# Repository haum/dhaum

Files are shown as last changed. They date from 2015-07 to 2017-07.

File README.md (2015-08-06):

# dHAUM

The dHAUM is a geodetic structure which can be used as a base for several projects.

The geodetic dome itself is a 5/8eme of a sphere structure, assembled using :

- 95 pieces of wood of 2 different types
- 36 connectors of 4 different types
- 190 bolts, nuts and washers

## Use cases

The dHAUM have been used to :

- create a huge group-played musical instrument : the [dHAUMidi](https://github.com/haum/dhaumidi)

## Repository

- ``doc/`` : documentation (build report, model, blueprint, etc...)
- ``parts/`` : DXF and milling gcodes for parts of the dome itself
- ``tools/ : DXF and milling gcodes for tools used to machine the wooden parts

Computation are done using the software [Zome Dome & Cie](http://www.ardheia.fr/ardheia/index.php/ressources).

Inside the ``doc/`` folder, you'll find :

- ``dHaum.zdc`` project file for the software
- ``Geodome.pdf`` building report generated by ZDC
- ``developpe.pdf``& ``developpe.dxf`` global plane developpement
- ``patron_4imp.pdf`` file to print 5 times to build a mock-up of the dHAUM at a 1/12.5 scale.
    Gluing works this way : capital letters must be glued on another print, lowercase letters must be glued on the same print but no strips are drawn : create yours. You should start by A, then B, a, C, D and finally b.

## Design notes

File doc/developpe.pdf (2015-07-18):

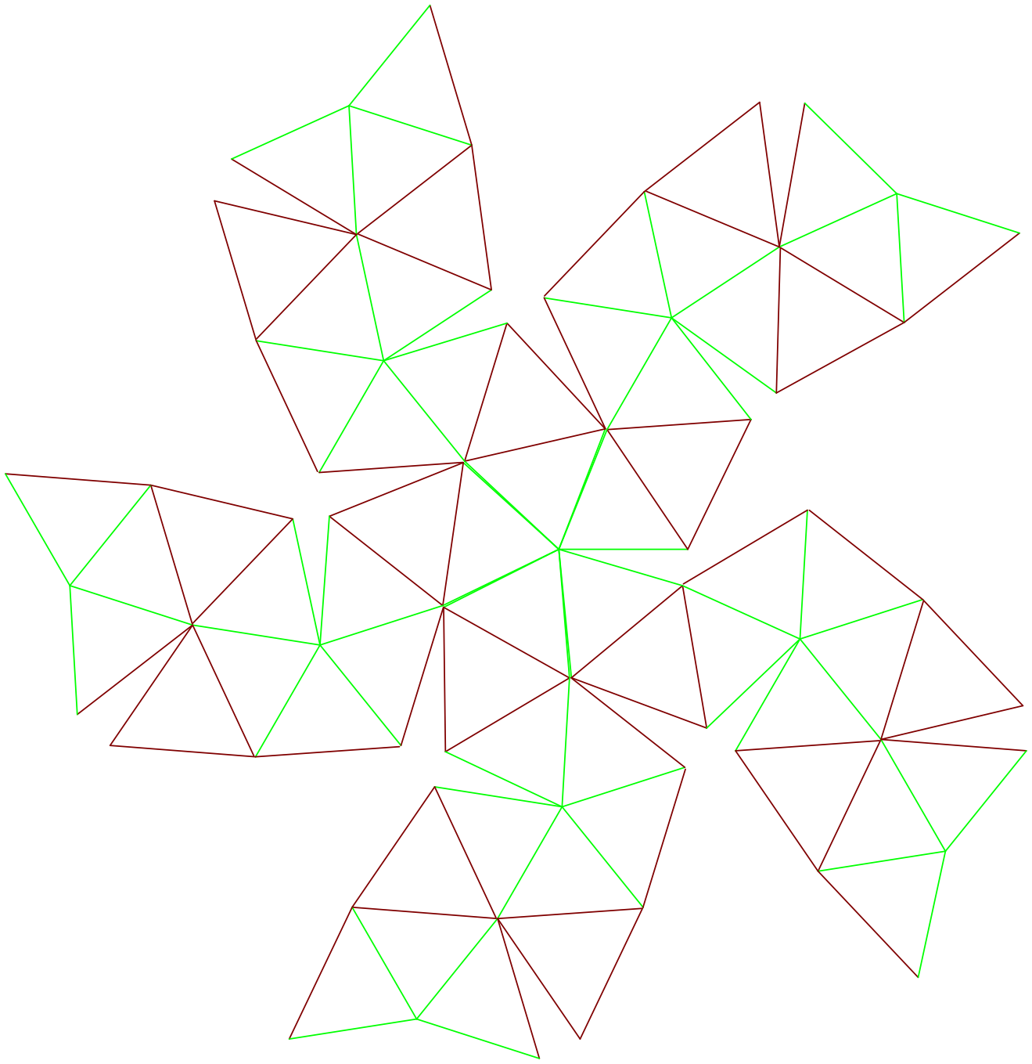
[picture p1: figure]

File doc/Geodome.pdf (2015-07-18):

# Compte-rendu technique d'un Geodome V 2 0

## Document généré automatiquement par le logiciel ZomeDomeEtCie (version 15.03.05)

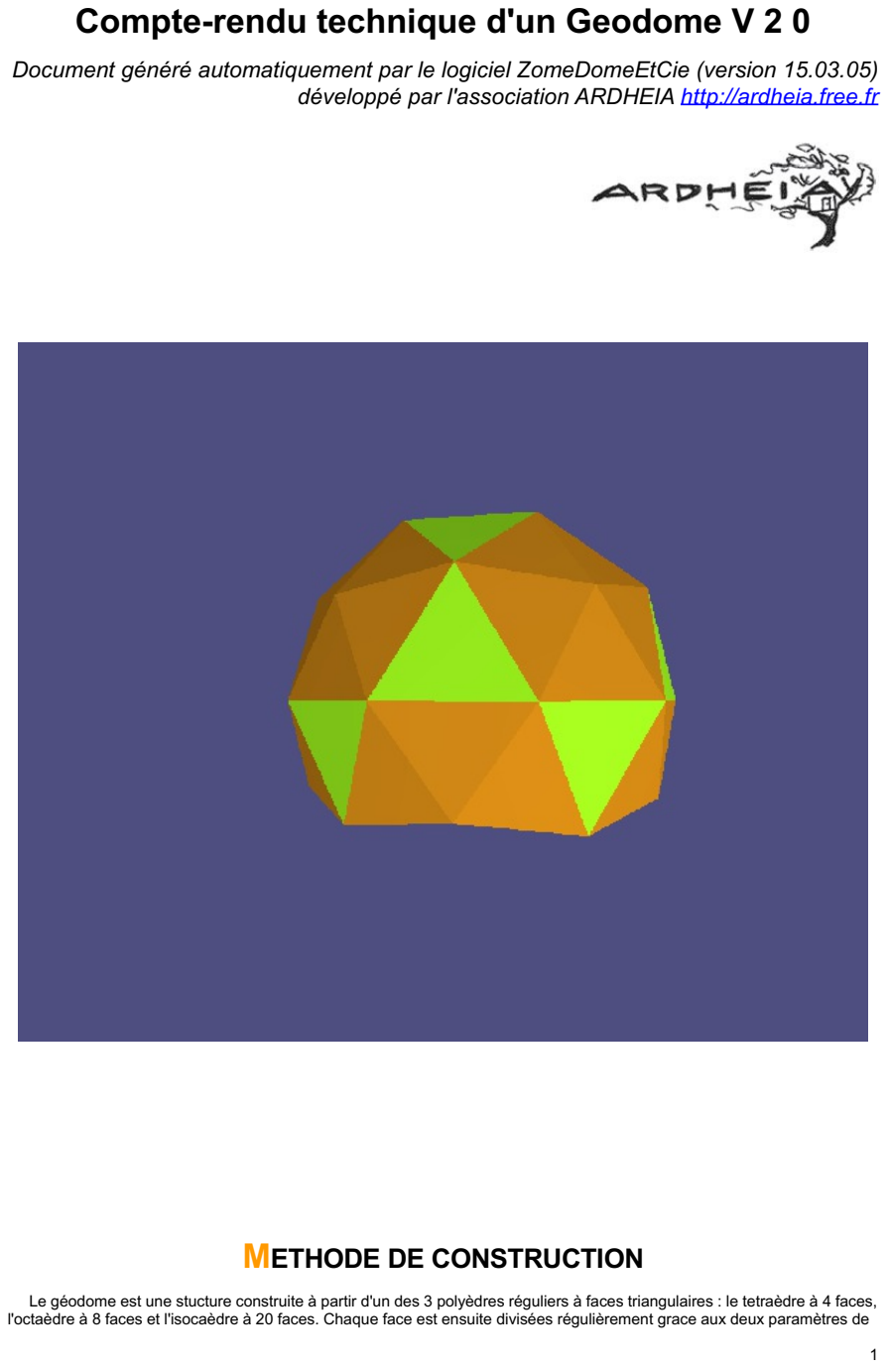
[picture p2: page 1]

## développé par l'association ARDHEIA http://ardheia.free.fr

## METHODE DE CONSTRUCTION

Le géodome est une stucture construite à partir d'un des 3 polyèdres réguliers à faces triangulaires : le tetraèdre à 4 faces, l'octaèdre à 8 faces et l'isocaèdre à 20 faces. Chaque face est ensuite divisées régulièrement grace aux deux paramètres de fréquence A et B. Les points obtenus sont ensuite projetés sur une sphère et reliés entre eux. Différentes méthodes sont possibles pour construire et assembler des géodomes. La documentation concernant les

géodomes (ou géodes, ou domes géodesiques) est abondante sur internet. Rappel des paramètres constructifs importants :

- Type de géodome : V 2 0 (chiffres romains pour indiquer solide de base : III pour tetraedre, IV pour octaedre, V pour isocaèdre; deuxième et troisième chiffres : fréquence A et fréquence B)
- Diamètre au sol, pour implantation : 2.38 m
- Diamètre de la sphère : 2.80 m
- Hauteur réelle, jusqu'au faîtage : 2.14 m
- Sablière horizontale : non
- Angle de rotation : 32°
- Surface au sol : 4.46 m²
- Surface de couverture : 17.15 m²
- Volume approché : 9.86 m3

## FACES

Le tableau suivant détaille les faces (f) du géodome : pour chaque type, il donne le nombre d'éléments, la surface, le type des 3 arêtes qui la constitue, leurs longueurs respectives, les mesures des 3 angles du triangle ainsi que la côte H qui peut être utile pour tracer les faces. Surface totale des faces (donc de toute la couverture du géodome) : 17.1 m². Les schémas suivants le tableau sont dessinés avec les bonnes côtes et angles, mais à échelle réduite bien sur.

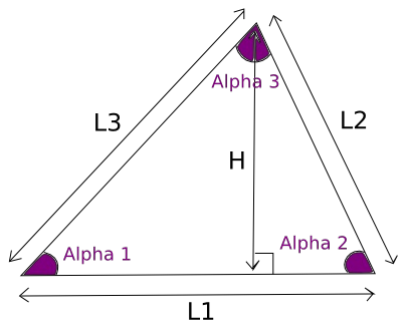
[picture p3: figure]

Type | Nombre | Surface (m2) | Type Arêtes | L1 (cm) | L2 (cm) | L3 (cm) | H (cm) | Alpha 1 (°) | Alpha 2 (°) | Alpha3 (°)

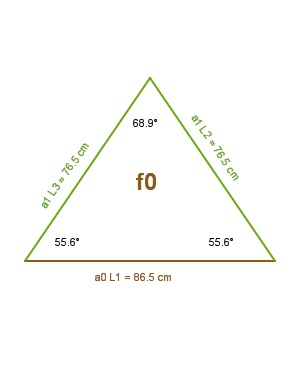
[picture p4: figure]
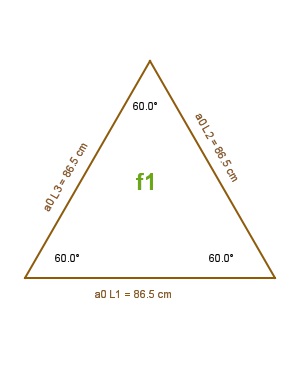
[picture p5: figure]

f0 | 45 | 0.27 | 0->1->1 | 86.5 | 76.5 | 76.5 | 63.1 | 55.6 | 55.6 | 68.9
f1 | 15 | 0.32 | 0->0->0 | 86.5 | 86.5 | 86.5 | 74.9 | 60.0 | 60.0 | 60.0
TOTAL | 60 | 17.15

## ARETES

Le tableau suivant détaille les arêtes (a) du géodome : pour chaque type, il donne le nombre d'éléments, leur longueur, ainsi que l'angle de bout. Cet angle est celui avec lequel il vont arriver sur le connecteur. Si vous travaillez avec des montants

en bois, il correspond à l'angle d'inclinaison de la scie pour couper les extrémités du montant. Attention, les longueurs sont données sans prendre en compte les éventuelles dimensions des connecteurs. Il faudra donc

en tenir compte pour tailler les montants, sinon vous allez simplement vous retrouver avec un géodome un peu plus grand. Métrage linéaire des montants (à multiplier par la section de vos montants pour avoir le débit) : 77.19 m.

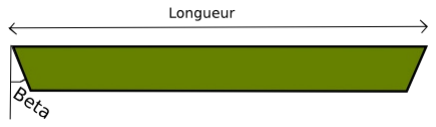
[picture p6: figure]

Type | Nombre | Longueur (cm) | Beta (°) | Rapport Longueur
a0 | 45 | 86.5 | 18.0 | 0.309017
a1 | 50 | 76.5 | 15.9 | 0.273267
TOTAL | 95 | 77.19 m

## SOMMETS

Le tableau suivant détaille les sommets (s) du géodome (ou connecteurs) : pour chaque type, il donne le nombre d'éléments, s'ils représentent un noeud complet ou un noeud qui n'a pas de faces tout autour de lui, le type des arêtes qui partent de ce noeud, le type des faces autour de ce noeud et les angles alpha'. Les données précedentes sont données pour chaque noeud, en tournant dans le sens horaire si on regarde le noeud depuis l'extérieur du géodome. Attention, les angles alpha' sont les angles projetés sur une surface plane (leur somme fait 360°), ce ne sont pas les

angles des différentes faces, ces derniers étant un peu inférieurs et donnés à l'onglet faces

Les schémas suivants le tableau sont dessinés avec les bons angles. Type | Nombre | Complet | Type Arêtes | Type Faces | Angles Alpha' ° s0 | 6 | oui | a1->a1->a1->a1->a1-> | f0->f0->f0->f0->f0-> | 72.0°->72.0°->72.0°->72.0°->72.0°->
s1 | 20 | oui | a0->a1->a0->a0->a1->a0-> | f0->f0->f1->f0->f0->f1-> | 58.3°->58.3°->63.4°->58.3°->58.3°- >63.4°->
s2 | 3 | non | a1->a1->a1->a1 | f0->f0->f0 | 72.0°->72.0°->72.0° s3 | 5 | non | a1->a0->a0->a1 | f0->f1->f0 | 58.3°->63.4°->58.3° s4 | 2 | non | a1->a1->a1 | f0->f0->f-1 | 72.0°->72.0° TOTAL | 36

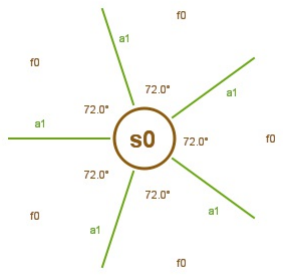
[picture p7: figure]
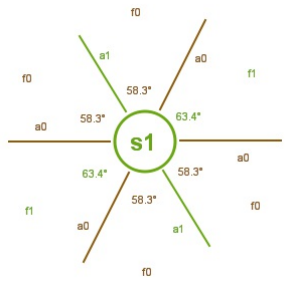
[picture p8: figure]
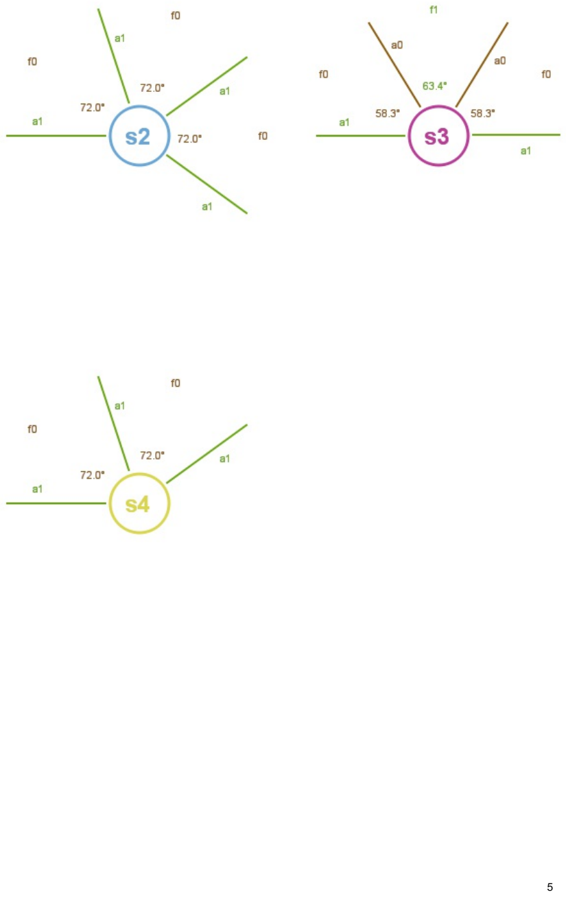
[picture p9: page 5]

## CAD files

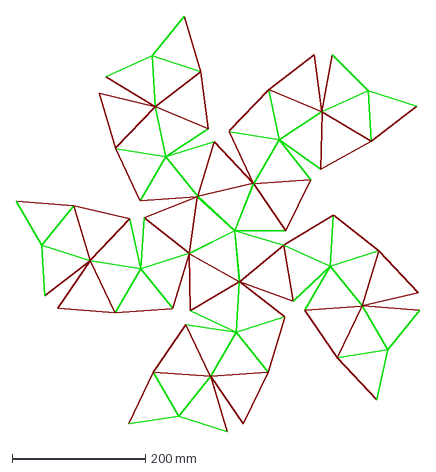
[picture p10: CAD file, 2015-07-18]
doc/developpe.dxf
605.8 x 624.2 mm

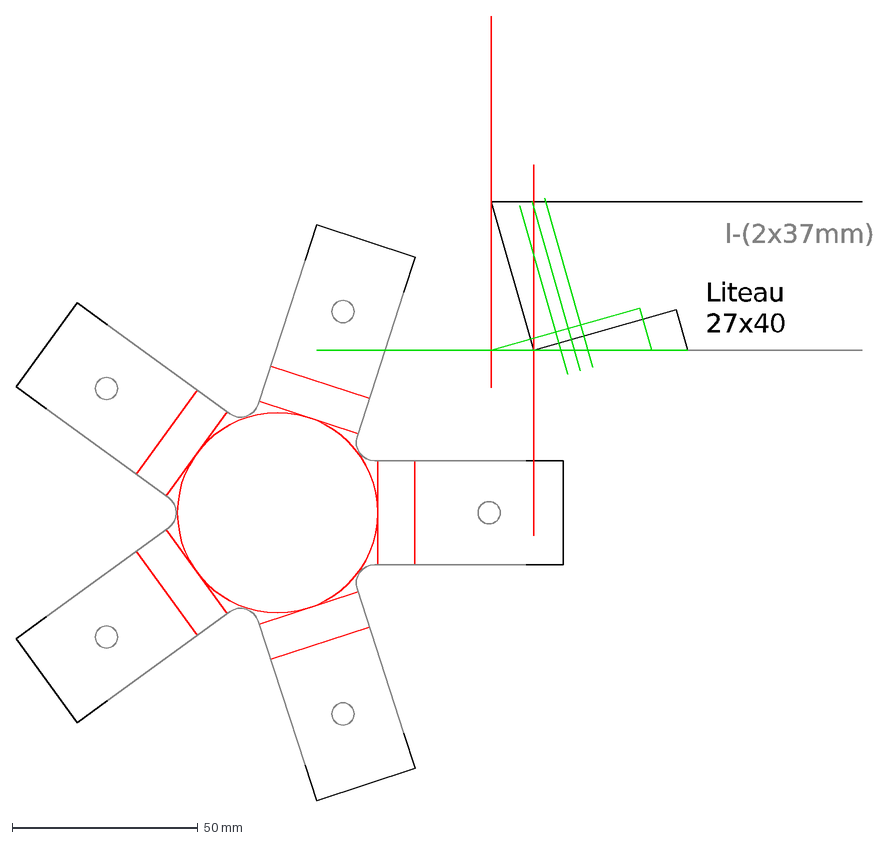
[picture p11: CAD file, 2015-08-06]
parts/connecteur0.dxf
l-(2x37mm)
Liteau 27x40

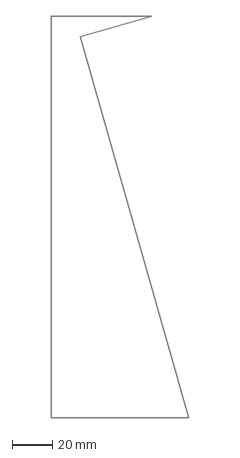
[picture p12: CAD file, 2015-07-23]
tools/sabot_15.9degres.dxf
68.5 x 200.0 mm

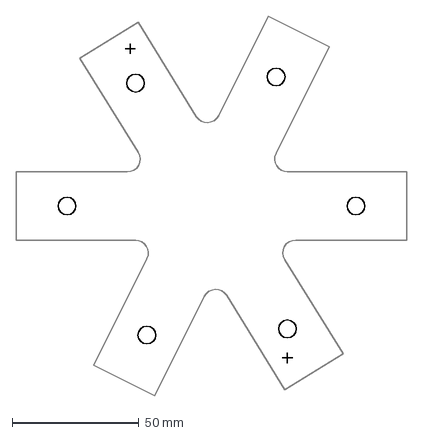
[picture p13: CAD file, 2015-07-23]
parts/connecteur1.dxf
154.0 x 149.8 mm

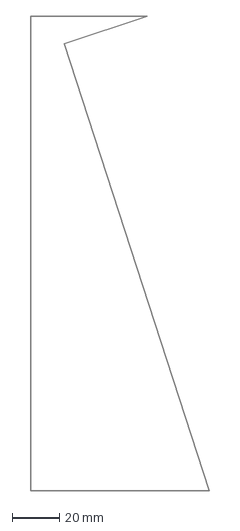
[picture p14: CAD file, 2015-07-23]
tools/sabot_18degres.dxf
75.3 x 200.0 mm

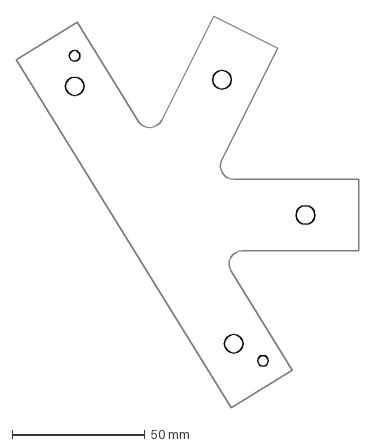
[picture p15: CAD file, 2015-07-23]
parts/connecteur3.dxf
128.9 x 147.5 mm

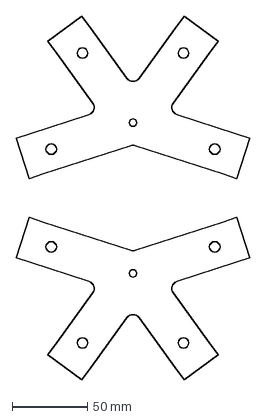
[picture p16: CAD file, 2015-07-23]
parts/connecteur24.dxf
155.1 x 241.0 mm

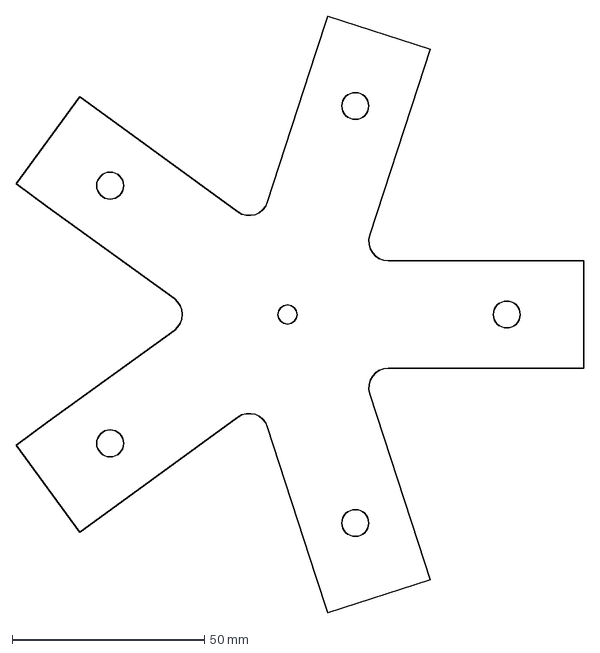
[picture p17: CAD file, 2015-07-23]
parts/connecteur0_cnc.dxf
147.5 x 155.1 mm

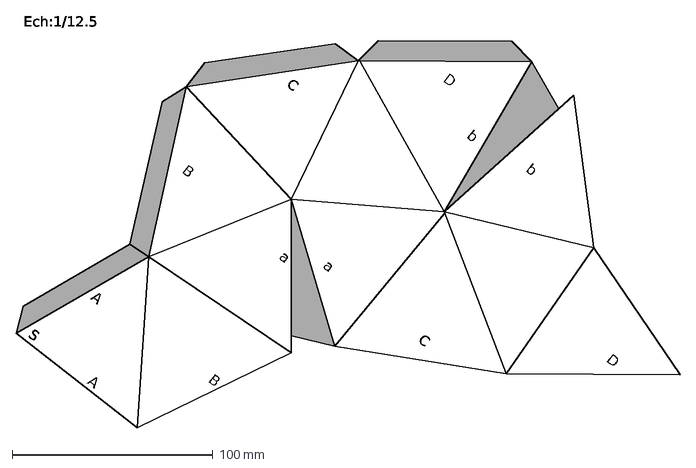
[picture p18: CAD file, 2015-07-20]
parts/geodHaum2_4imp.dxf
S
A
B
a
b
C
D
Ech:1/12.5

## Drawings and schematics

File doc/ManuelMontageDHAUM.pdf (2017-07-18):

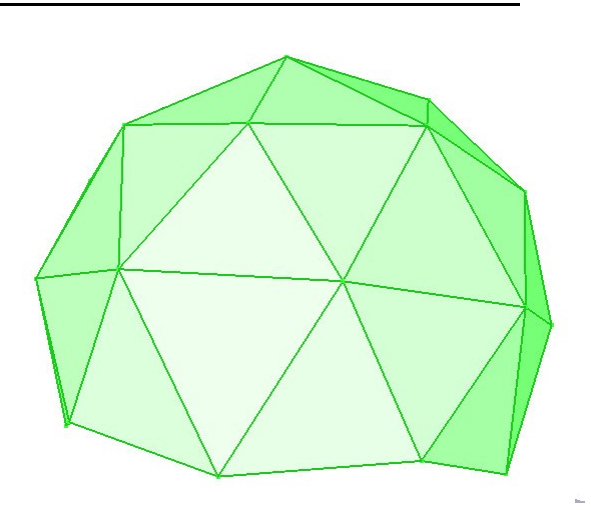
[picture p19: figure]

# Guide d'assemblage du dHAUM

### 1. Assemblage

Le dHAUM reproduit les 5/8 d'une sphère, en concéquence afin de faciliter la lecture des intructions de montage, ces dernières sont séparées en deux partie.

A. En partant de la base du dHAUM jusque son diamètre maxi. (a l'équateur).
B. Puis de ce point jusqu'au sommet

Légende :

Tasseaux courts
Tasseaux Longs
Connecteurs de type 1 (6 branches)

Connecteurs de type 2 (5 branches)

Connecteurs de type 3 (4 branches droit)

Connecteurs de type 4 (4 branches bas)

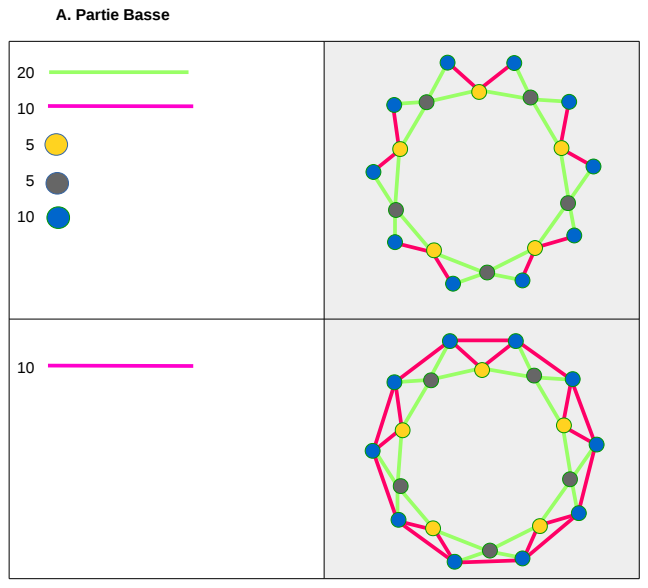
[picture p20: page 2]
A. Partie Basse

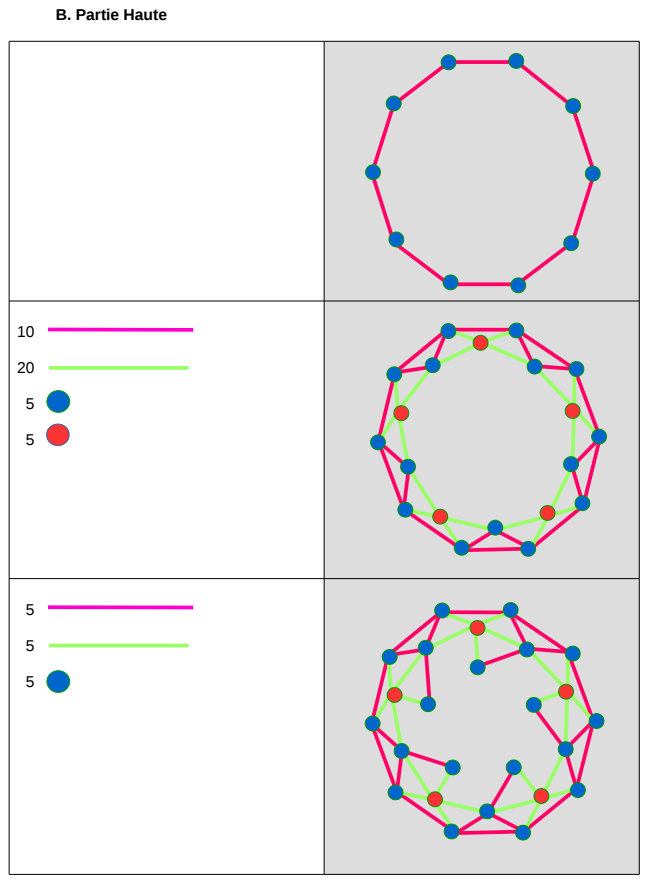
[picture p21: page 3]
B. Partie Haute

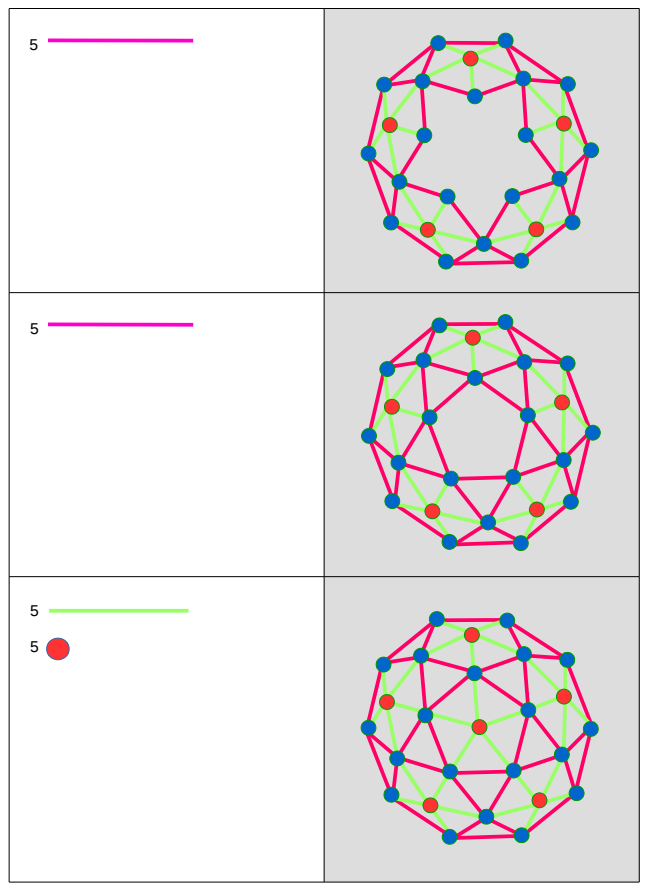
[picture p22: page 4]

### 2. Portes et Entoilage

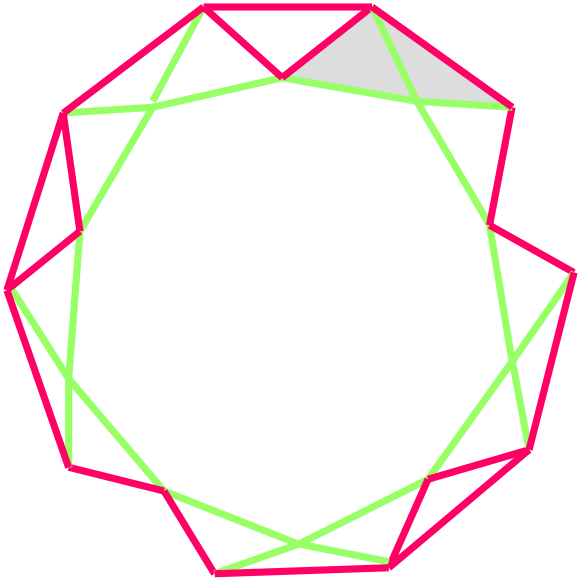
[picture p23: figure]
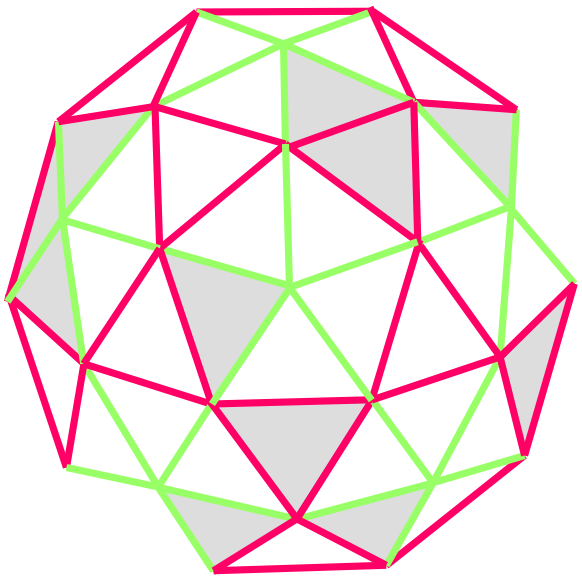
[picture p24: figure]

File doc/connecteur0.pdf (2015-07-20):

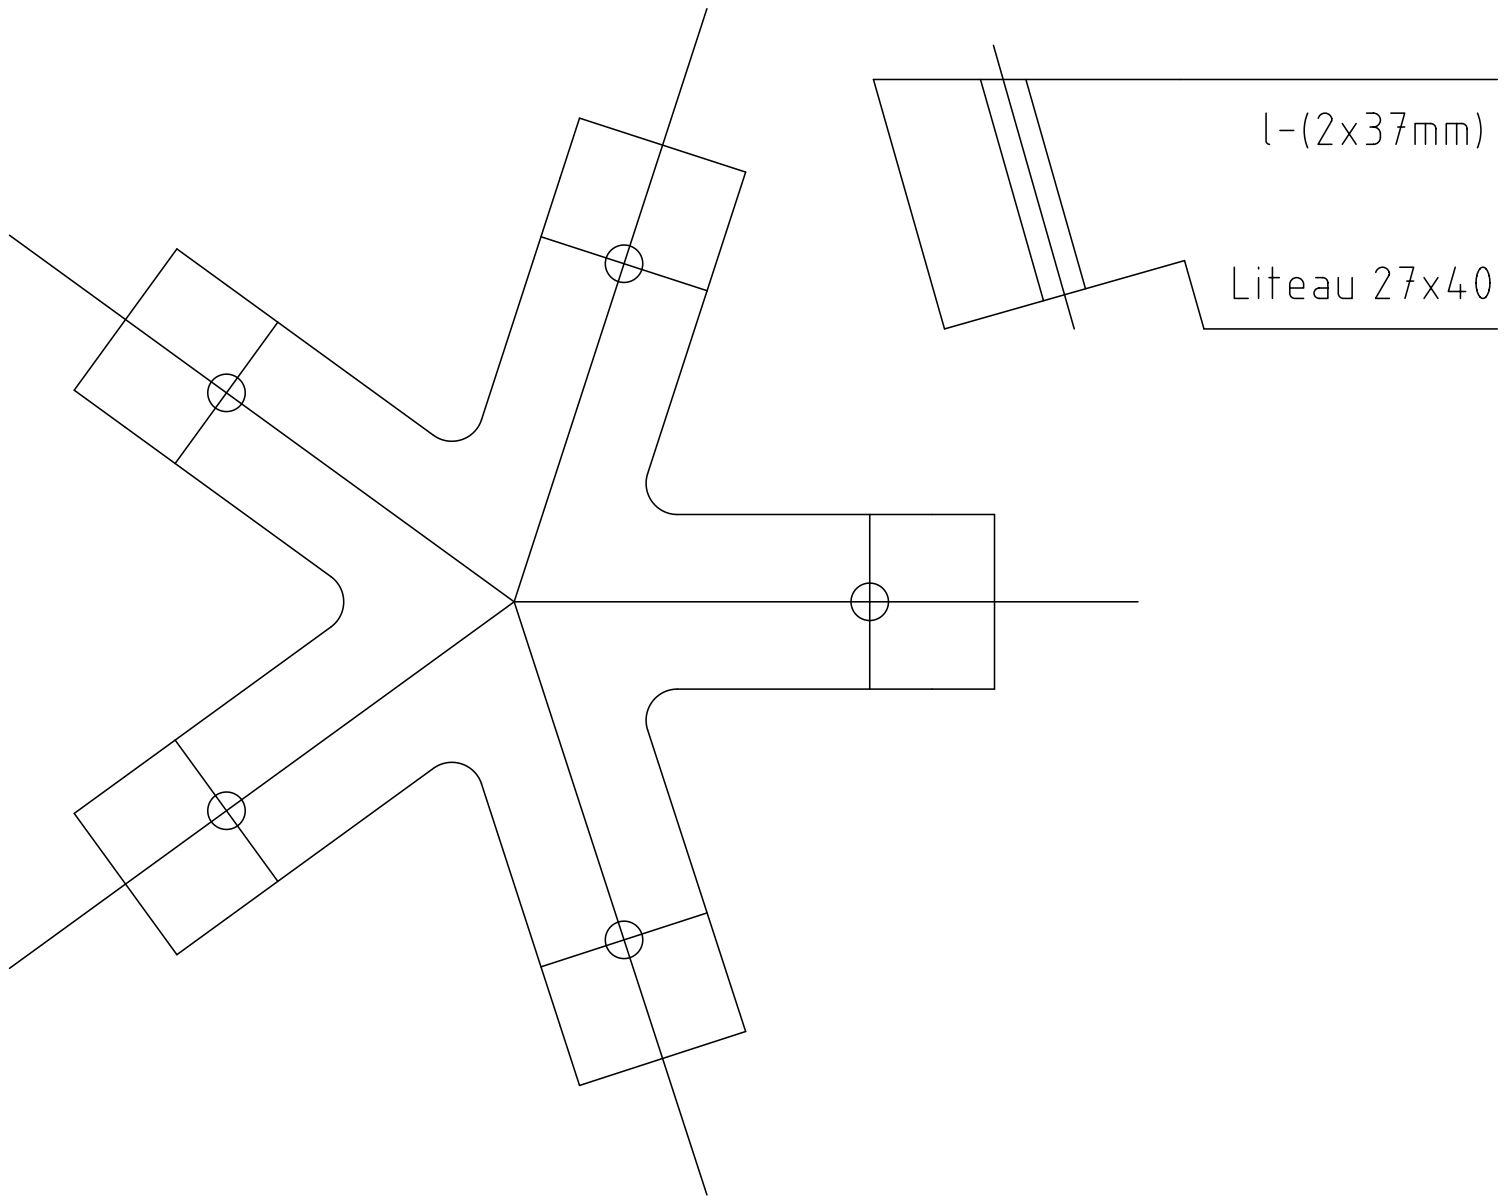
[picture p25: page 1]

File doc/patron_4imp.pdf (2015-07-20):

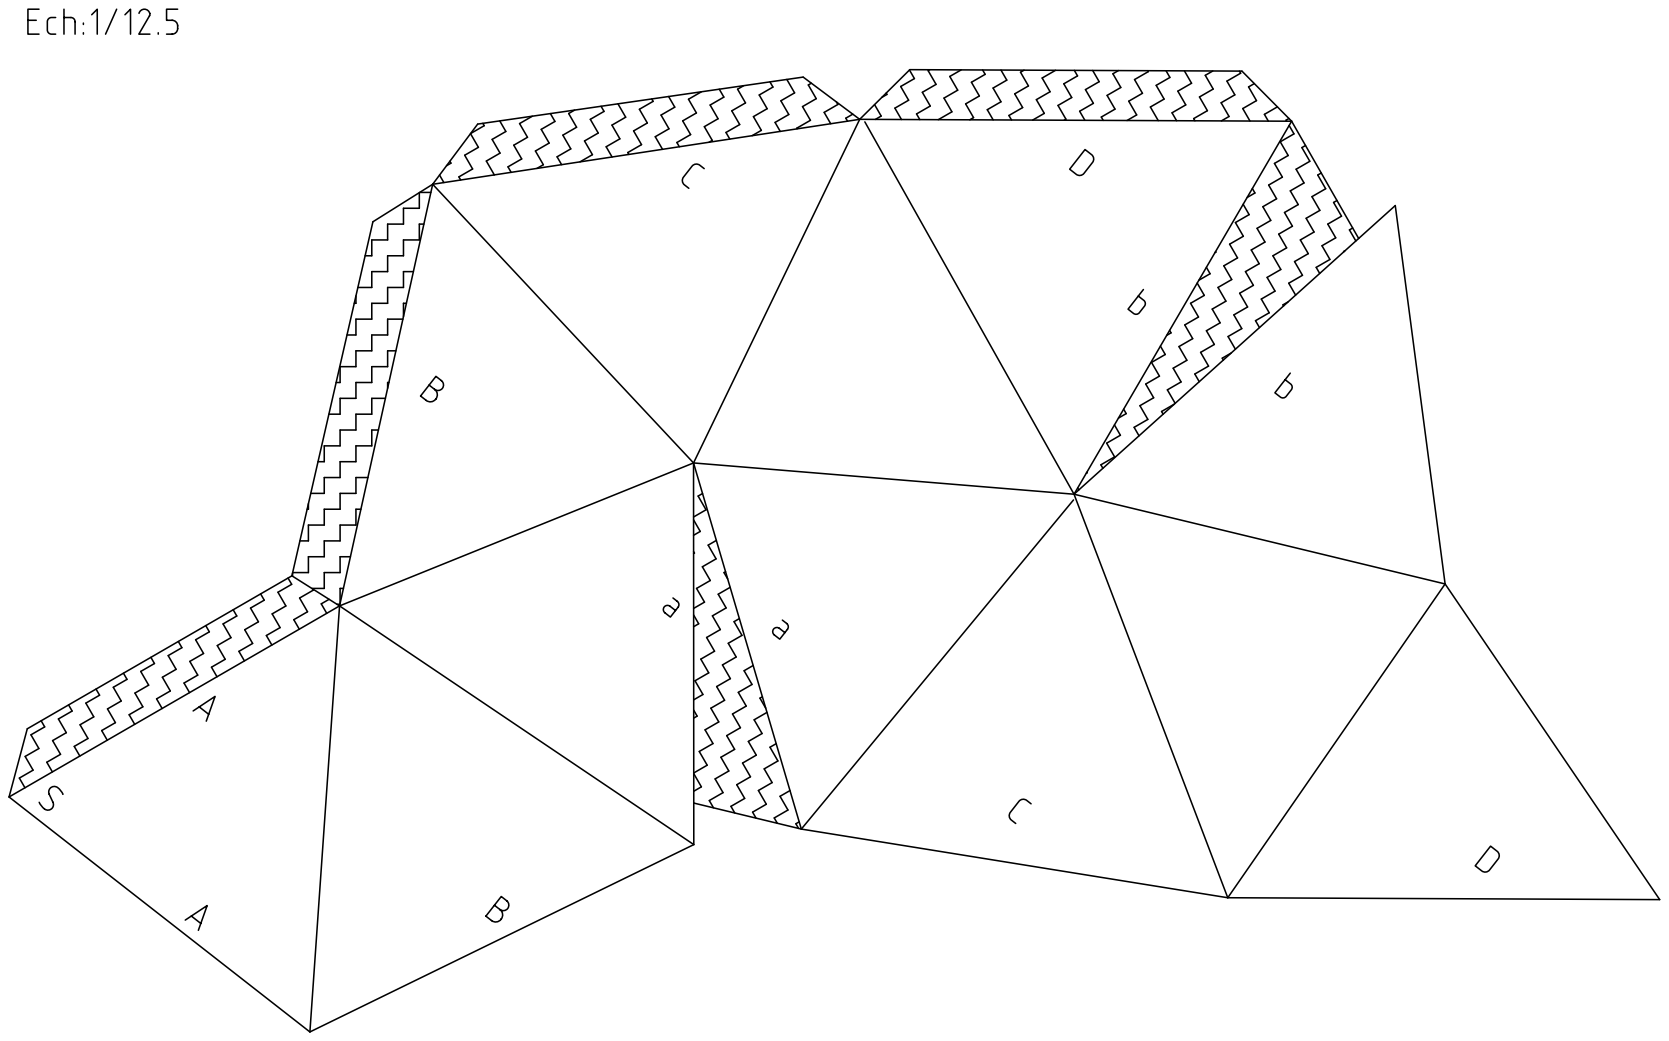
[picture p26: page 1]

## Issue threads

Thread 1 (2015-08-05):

Ajouter une sortie hardware MIDI

jblb, 2015-08-05:
il s'agit, en plus de la connexion MIDI a travers l'USB, de disposer d'une sortie MIDI sur une prise Dim/5broches qui sorte les même valeurs MIDI que l'interface USB. De cette façon deux récepteurs peuvent utiliser le code généré par l'interface.

JackDesBwa, 2015-08-05:
Il y a une seule broche de la Léoké qui n'est pas utilisable avec les
touches "tactiles". Elle est numérotée L0 et doit être au niveau logique
bas au démarrage de la carte (il y a une pull-down) pour que ça démarre au
bon endroit dans la flash. Elle peut parfaitement être employée en sortie
si l'impédance en face est compatible.

Après faudrait trouver une lib qui puisse générer un signal midi sur une
gpio sans occuper trop de CPU. Ou alors sacrifier des broches pour utiliser
une vraie liaison série.

Sinon on peut aussi faire un pass-through sur le PC, ce serait certainement
moins contraignant.
Le 5 août 2015 11:05, "JbLb" <notifications@github.com> a écrit :

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

neomilium, 2015-08-05:
Le MIDI 'old-school' est plus ou moins un UART à 31250 bauds. Il faut donc utiliser les pins UART pour faire cela sans trop consommer de CPU.

Pour ma part, je ne vois pas l'intérêt : pourquoi ne pas passer par l'ordinateur qui multiplexe ensuite vers autant de sorties qu'utiles, avec ou sans transformation intermédiaire :)

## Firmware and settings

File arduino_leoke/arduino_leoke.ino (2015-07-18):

/* To be used with Léoké */

#define PADBIT(PAD) (1 << (PAD-1))
#define PADSNB (sizeof(L)/sizeof(*L))

#define DEBUG_RAW_CODE 0

typedef enum {
  UNTOUCHED, // Not touched at all
  TOUCHED, // Touched this loop
  LASTTOUCHED, // Touched last loop
} touchstatus_e;

struct binder_s {
  uint32_t bits;
  uint32_t mask;

  touchstatus_e touched;
  char debounce;
  touchstatus_e touched_filtered;
} binders[] = {
  { PADBIT(1) | PADBIT(2), 0xffffffff, },
  { PADBIT(5) | PADBIT(6), 0xffffffff, },
};

#define BINDERNB (sizeof(binders)/sizeof(*binders))
#define MAXDEBOUNCE 5

void setup() {
  // All others are input and untouched
  for (int i = 0; i < PADSNB; ++i) {
    pinMode(L[i], INPUT);
    digitalWrite(L[i], LOW);
  }

  // Reset binders
  for (int i = 0; i < BINDERNB; ++i) {
    binders[i].touched = UNTOUCHED;
    binders[i].debounce = 0;
  }

  // Services begin
  Serial.begin(115200);
}

void loop() {
  // For each key
  uint32_t active = 1; // Current bit operated
  for (int i = 1; i < PADSNB; ++i) {
    uint32_t pushed = active; // Bitfield of pressed pads
    uint32_t bitj = active; // Current bit in inner loop

    // Activate ith pad
    pinMode(L[i], OUTPUT);

    // Detect active pads
    for (int j = i + 1; j < PADSNB; ++j) {
      bitj <<= 1;
      if (!digitalRead(L[j]))
        pushed |= bitj ;
    }

    // Debug show multi presses
    if (active != pushed && DEBUG_RAW_CODE) {
      Serial.print("Code : ");
      Serial.println(pushed, HEX);
    }

    // Detect touch events
    for (int j = 0; j < BINDERNB; ++j) {
      binder_s & binder = binders[j];
      touchstatus_e touched = ((binder.bits & binder.mask) == (pushed & binder.mask)) ? TOUCHED : UNTOUCHED;
      if (touched == TOUCHED)
        binder.touched = TOUCHED;
    }

    // Deactivate ith pad
    pinMode(L[i], INPUT);
    active <<= 1;
  }

  // Detect untouch events + debounce
  for (int j = 0; j < BINDERNB; ++j) {
    binder_s & binder = binders[j];
    if (binder.touched == LASTTOUCHED) {
      binder.touched = UNTOUCHED;

    } else if (binder.touched == TOUCHED) {
      binder.touched = LASTTOUCHED;
    }

    binder.debounce += (binder.touched == UNTOUCHED) ? -1 : 1;
    if (binder.debounce > MAXDEBOUNCE)
      binder.debounce = MAXDEBOUNCE;
    if (binder.debounce < 0)
      binder.debounce = 0;
      if (binder.debounce == MAXDEBOUNCE && binder.touched_filtered == UNTOUCHED) {
        Serial.print("On ");
        Serial.println(binder.bits, HEX);
        binder.touched_filtered = LASTTOUCHED;
      } else if (binder.debounce == 0 && binder.touched_filtered != UNTOUCHED) {
        Serial.print("Off ");
        Serial.println(binder.bits, HEX);
        binder.touched_filtered = UNTOUCHED;
      }
  }

  // Debug separator
  if (DEBUG_RAW_CODE)
    Serial.println("==");

  // Debounce
  delay(5);
}

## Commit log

2015-07-17 arduino: first (not working) version
    [arduino_leoke.ino]
2015-07-17 arduino: place sketch in the right directory
2015-07-17 arduino: whaooo, our own heart beats are visible in the noise WTF
    [arduino_leoke.ino]
2015-07-18 arduino: correct event detection mechanism
    [arduino_leoke.ino]
2015-07-18 arduino: add define to hide raw debug
2015-07-18 arduino: add more efficient debounce mechanism
2015-07-18 arduino: split code and rename sketch
2015-07-18 arduino: add midi
2015-07-18 arduino: big review
2015-07-18 jout des fichiers de fabrication d'une maquette du dHaum
    [geodHaum2.dxf, geodHaum2_4imp.dxf]
2015-07-20 Correction couleurs pour impression N&B. Reperage languesttes de collage.
    [geodHaum2_4imp.dxf]
2015-07-20 Plan du connecteur 0 et dimenssion d'une arrete
    [connecteur0.dxf]
2015-07-21 arduino: prevent from parasitic capacitance
2015-07-21 arduino: more reactive filter
2015-07-23 ajout dessin connecteurs
    [connecteur0_cnc.dxf, connecteur24.dxf, connecteur3.dxf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]
2015-07-23 ajout connecteurs
    [connecteur1.dxf]
2015-07-23 ajout marquage branches courte
    [connecteur1.dxf, connecteur3.dxf]
2015-08-04 Add connector S1 (heeks and ngc)
2015-08-06 Re-organization of repos
    [connecteur0.dxf, connecteur0_cnc.dxf, connecteur1.dxf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]
2016-04-11 Ajout du guide de montage du dHAUM
2017-07-18 pdf du Manuel de Montage du DHAUM
